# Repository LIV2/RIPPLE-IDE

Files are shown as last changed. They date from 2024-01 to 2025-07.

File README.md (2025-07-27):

# RIPPLE IDE

Zorro 2 IDE Interface for Amiga 2000/3000/4000

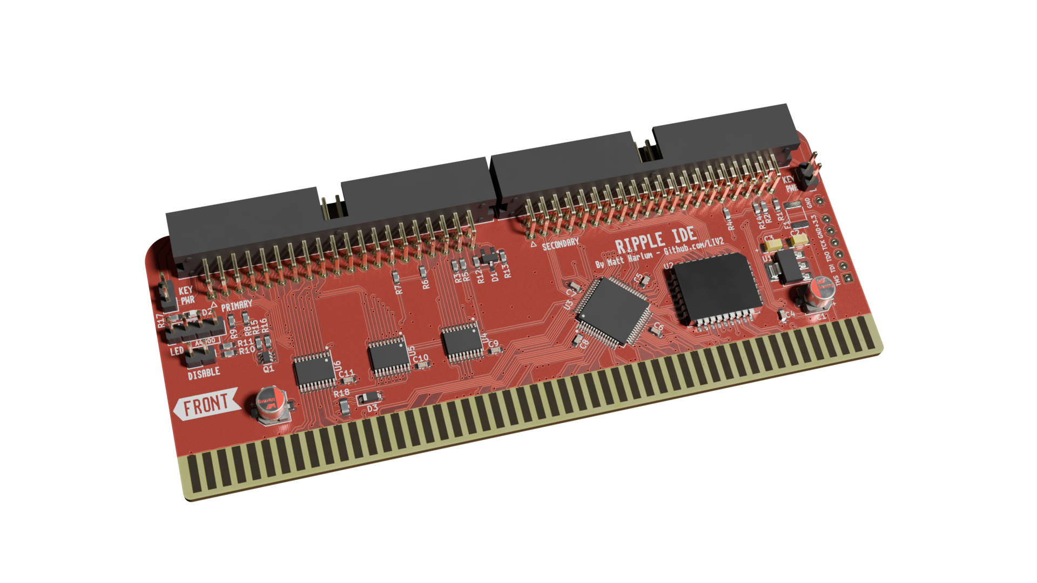
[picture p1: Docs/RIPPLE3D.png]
PCB


## Table of contents
1. [Status](#status)
2. [Features](#features)
3. [Jumpers](#jumpers)
4. [Ordering PCBs](#ordering-pcbs)
5. [Programming](#programming)
6. [Parts list & Links](#parts-list--links)
7. [Revision history](#revision-history)
8. [Special Thanks and Shoutouts](#special-thanks-and-shoutouts)
9. [License](#license)

## Status
Tested and working.

## Features
* Autoboot
* ROM can be updated simply by booting the update disk
* Works with Kickstart 1.3 and up
* [Supports up to 2TB drives](https://github.com/LIV2/lide.device/#large-drive-4gb-support)
* Supports ATAPI Devices (CD/DVD-ROM, Zip disk etc)
* Boot from ZIP/LS-120 etc
* [Boot from CD-ROM](https://github.com/LIV2/lide.device/#boot-from-cdrom)
* SCSI Direct, NSD, TD64 support
* Uses [lide.device](https://github.com/LIV2/lide.device)

For more information on these features please see the [lide.device readme](https://github.com/LIV2/lide.device/blob/master/README.md)

## Jumpers
|Jumper|Function|
|---|---|
|**DISABLE**| Disables the IDE interface|
|**LED**|The LED header has two positions: A2000 and A4000<br /> Plug the HDD LED connector into the one relevant for your machine|
|**KEY PWR**|Closing this jumper enables 5V power on pin 20 for CompactFlash/IDE DOM modules|

## Ordering PCBs
You can find the latest Gerbers attached to the [latest Release](https://github.com/LIV2/RIPPLE-IDE/releases)

I recommend ordering from JLCPCB as this board was designed within their 2-layer specifications  

BOM and Placement files for JLCPCBs assembly service are provided and can be found inside the Gerbers folder and the Gerbers.zip file found under [Releases](https://github.com/LIV2/RIPPLE-IDE/releases)

Recommended options when ordering:
* Thickness: 1.6mm
* Surface Finish: ENIG-RoHS
* Gold Fingers: Yes
* 45°finger chamfered: Yes

## Programming
To program the Flash, simply boot the latest [lide-update.adf](https://github.com/LIV2/lide.device/releases/latest) boot disk

The CPLD can be programmed using a Raspberry Pi [as described by LinuxJedi](https://linuxjedi.co.uk/2020/12/01/programming-xilinx-jtag-from-a-raspberry-pi/)

## Parts list & links
### Rev A4
* [HTML BOM](https://html-preview.github.io/?url=https://github.com/LIV2/RIPPLE-IDE/blob/Rev_A4/Docs/RIPPLE_bom.html)
* [Interactive HTML BOM](https://html-preview.github.io/?url=https://github.com/LIV2/RIPPLE-IDE/blob/Rev_A4/Docs/RIPPLE-ibom.html)

### Rev A3
* [HTML BOM](https://html-preview.github.io/?url=https://github.com/LIV2/RIPPLE-IDE/blob/Rev_A3/Docs/RIPPLE_bom.html)
* [Interactive HTML BOM](https://html-preview.github.io/?url=https://github.com/LIV2/RIPPLE-IDE/blob/Rev_A3/Docs/RIPPLE-ibom.html)

### Rev A2 & A1
* [BOM](Docs/Rev_A2-bom.md)
* [Interactive HTML BOM](https://html-preview.github.io/?url=https://github.com/LIV2/RIPPLE-IDE/blob/Rev_A2/Docs/RIPPLE-ibom.html)

## Revision history
* A4 - Change flash footprint from TSOP to PLCC because the TSOP version is no longer manufactured.
* A3 - Add protection for reverse installation
* A2 - Add bank selection, support loading CDFS from flash
* A1 - Initial release

## Special Thanks and Shoutouts
Thanks to:
* GadgetUK164, Screemo, Sparx, Mafitzee, Pillock for Beta testing the board
* Stefan Reinauer and Chris Hooper for creating the Open-Source A4091 driver which was the inspiration to create lide.device used by RIPPLE

## License
RIPPLE IDE is covered by a GPL 2.0 Only license  


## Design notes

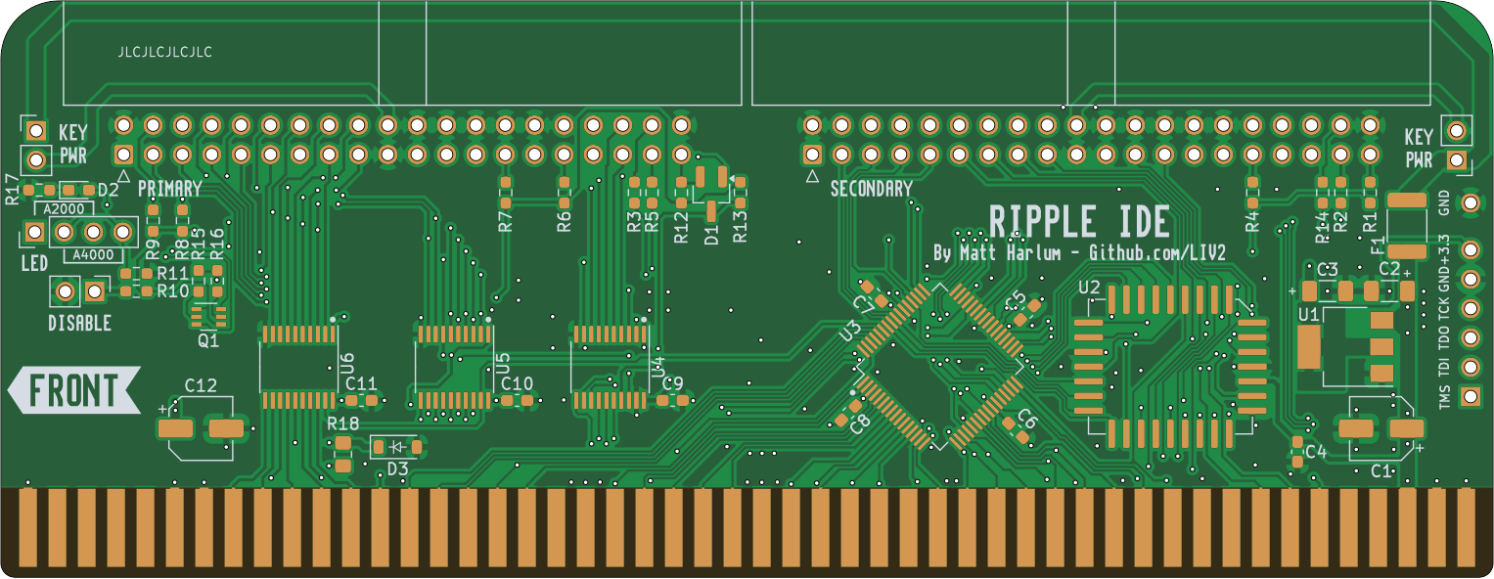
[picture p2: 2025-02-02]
Docs/PCB.png

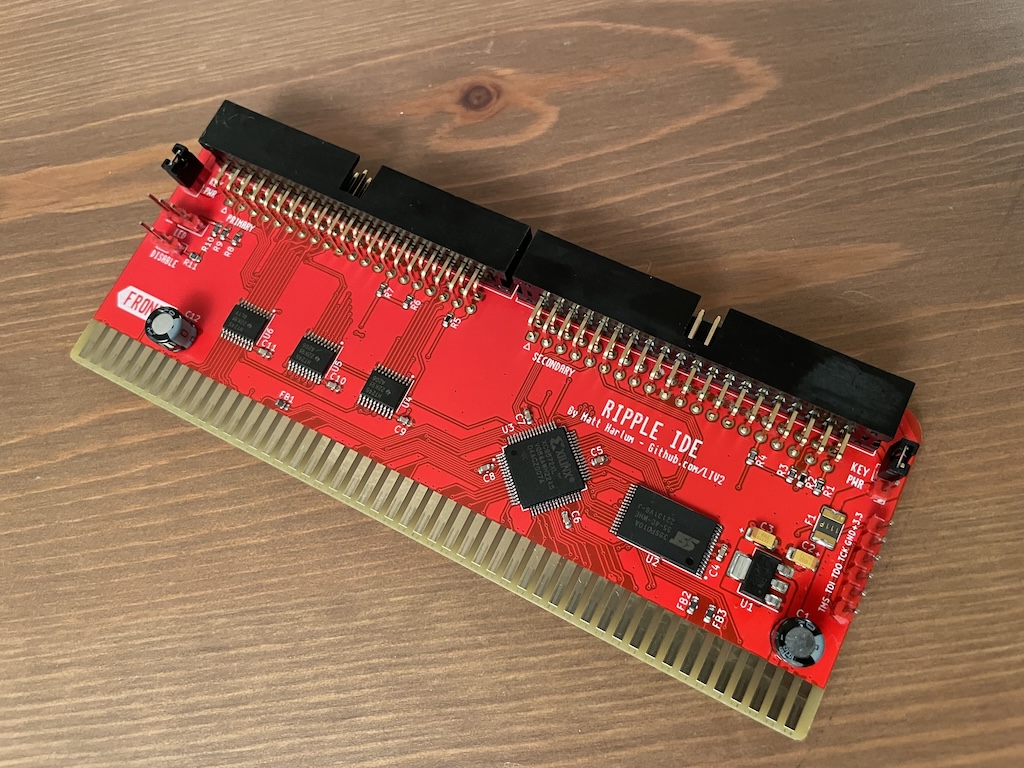
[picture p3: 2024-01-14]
Docs/RIPPLE.jpg

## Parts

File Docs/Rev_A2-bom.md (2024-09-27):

## Bill of Materials
|References|Qty|Value|Footprint|Link|
|---|---|-----|---|----|
|C1,C12|2|47uF 16V|CP_Radial_D5.0mm_P2.50mm|[Mouser](https://www.mouser.com/ProductDetail/667-ECE-A1CKA470I)|
|C3,C2|2|10uF Tantalum|1206|[Mouser](https://www.mouser.com/ProductDetail/581-TAJA106K016R)|
|C9,C4,C5,C7,C11,C8,C6,C10|8|0.1uF Ceramic|0603|[Mouser](https://www.mouser.com/ProductDetail/187-CL10B104KA8NFNC)|
|D1|1|BAT54A|SOT-23|[Mouser](https://www.mouser.com/ProductDetail/621-BAT54A-F)|
|D2|1|SMD LED|0603|[Mouser](https://www.mouser.com/ProductDetail/710-150060VS75000)|
|F1|1|2A Polyfuse|1812|[Mouser](https://www.mouser.com/ProductDetail/652-MF-MSMF110-16-2)|
|J1|1|JTAG Header|1x06 2.54mm Pin Header||
|J4,J3|2|IDE Connector, Right-angle|2x20 2.54mm Right-angle IDC|[Mouser](https://www.mouser.com/ProductDetail/517-30340-5002)|
|J5|1|Disable Jumper|1x02 2.54mm Pin Header||
|J6|1|LED Header|1x04 2.54mm Pin Header||
|J7,J2|2|KEY_PWR|1x02 2.54mm Pin Header||
|Q1|1|BC857BS|SOT-363|[Mouser](https://www.mouser.com/ProductDetail/621-BC857BS-13-F)|
|R10|1|150 Ohm|0603|[Mouser](https://www.mouser.com/ProductDetail/603-RC0603FR-10150RL)|
|R12,R1,R8,R13,R11,R9|6|10K Ohm|0603|[Mouser](https://www.mouser.com/ProductDetail/279-CRGH0603J10K)|
|R14,R5,R2,R3|4|68 Ohm|0603|[Mouser](https://www.mouser.com/ProductDetail/71-CRCW060368R0FKEB)|
|R17|1|330 Ohm|0603|[Mouser](https://www.mouser.com/ProductDetail/603-RT0603DRE07330RL)|
|R6,R4,R15,R16,R7|5|1K Ohm|0603|[Mouser](https://www.mouser.com/ProductDetail/603-RC0603JR-131KL)|
|U1|1|LM1117-3.3|SOT-223-3|[Mouser](https://www.mouser.com/ProductDetail/926-LM1117MP-3.3NOPB)|
|U2|1|SST39SF010|TSOP-32|[Mouser](https://www.mouser.com/ProductDetail/579-SST39010A554CWHE)|
|U3|1|XC9572XL-VQ64|VQFP-64|[Mouser](https://www.mouser.com/ProductDetail/217-C9572XL-10VQG64C)|
|U6,U5,U4|3|74HCT245|TSSOP-20|[Mouser](https://www.mouser.com/ProductDetail/595-SN74HCT245PWR)|

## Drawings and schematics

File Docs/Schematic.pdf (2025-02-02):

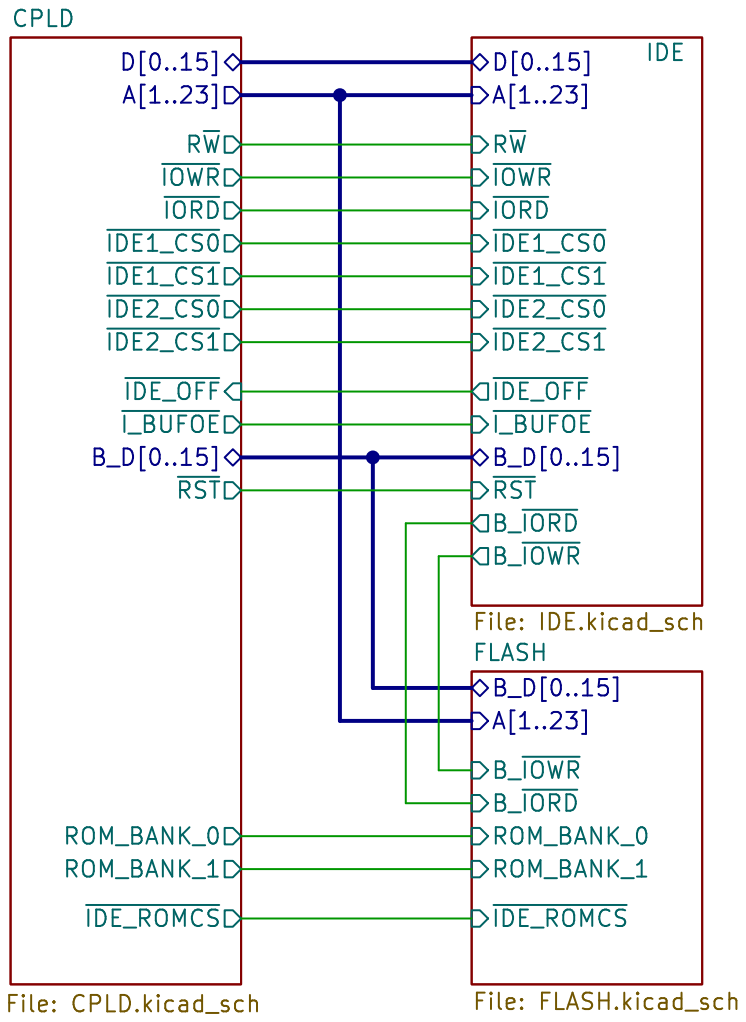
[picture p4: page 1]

Id: 1/4 Title: File: RIPPLE.kicad_sch Sheet: /

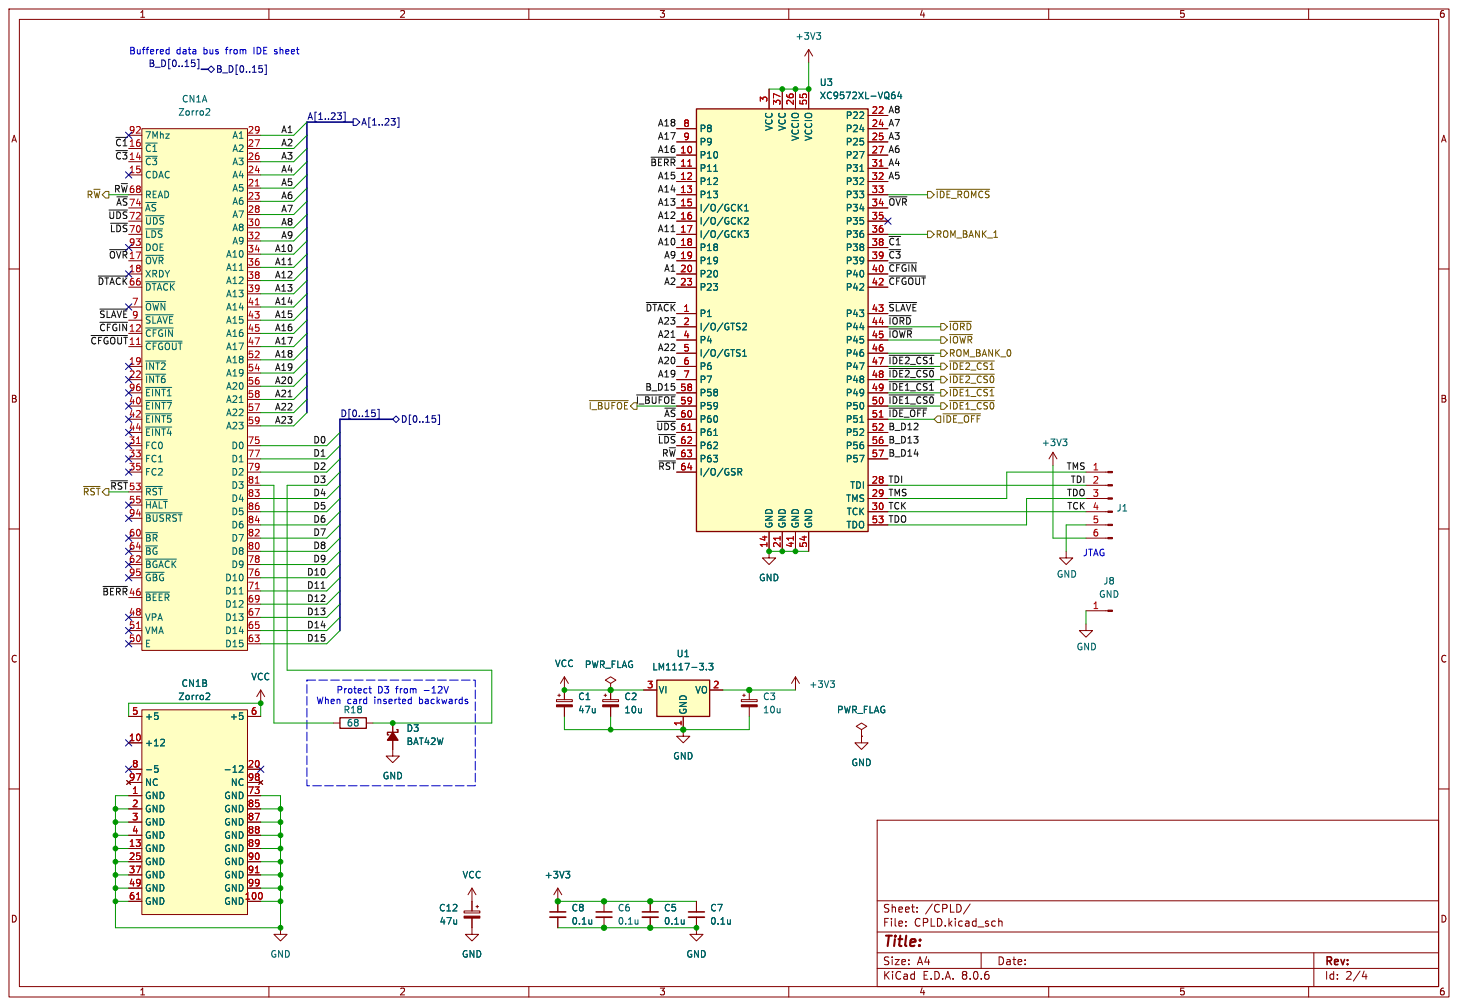
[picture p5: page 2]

Id: 2/4 Title: File: CPLD.kicad_sch Sheet: /CPLD/

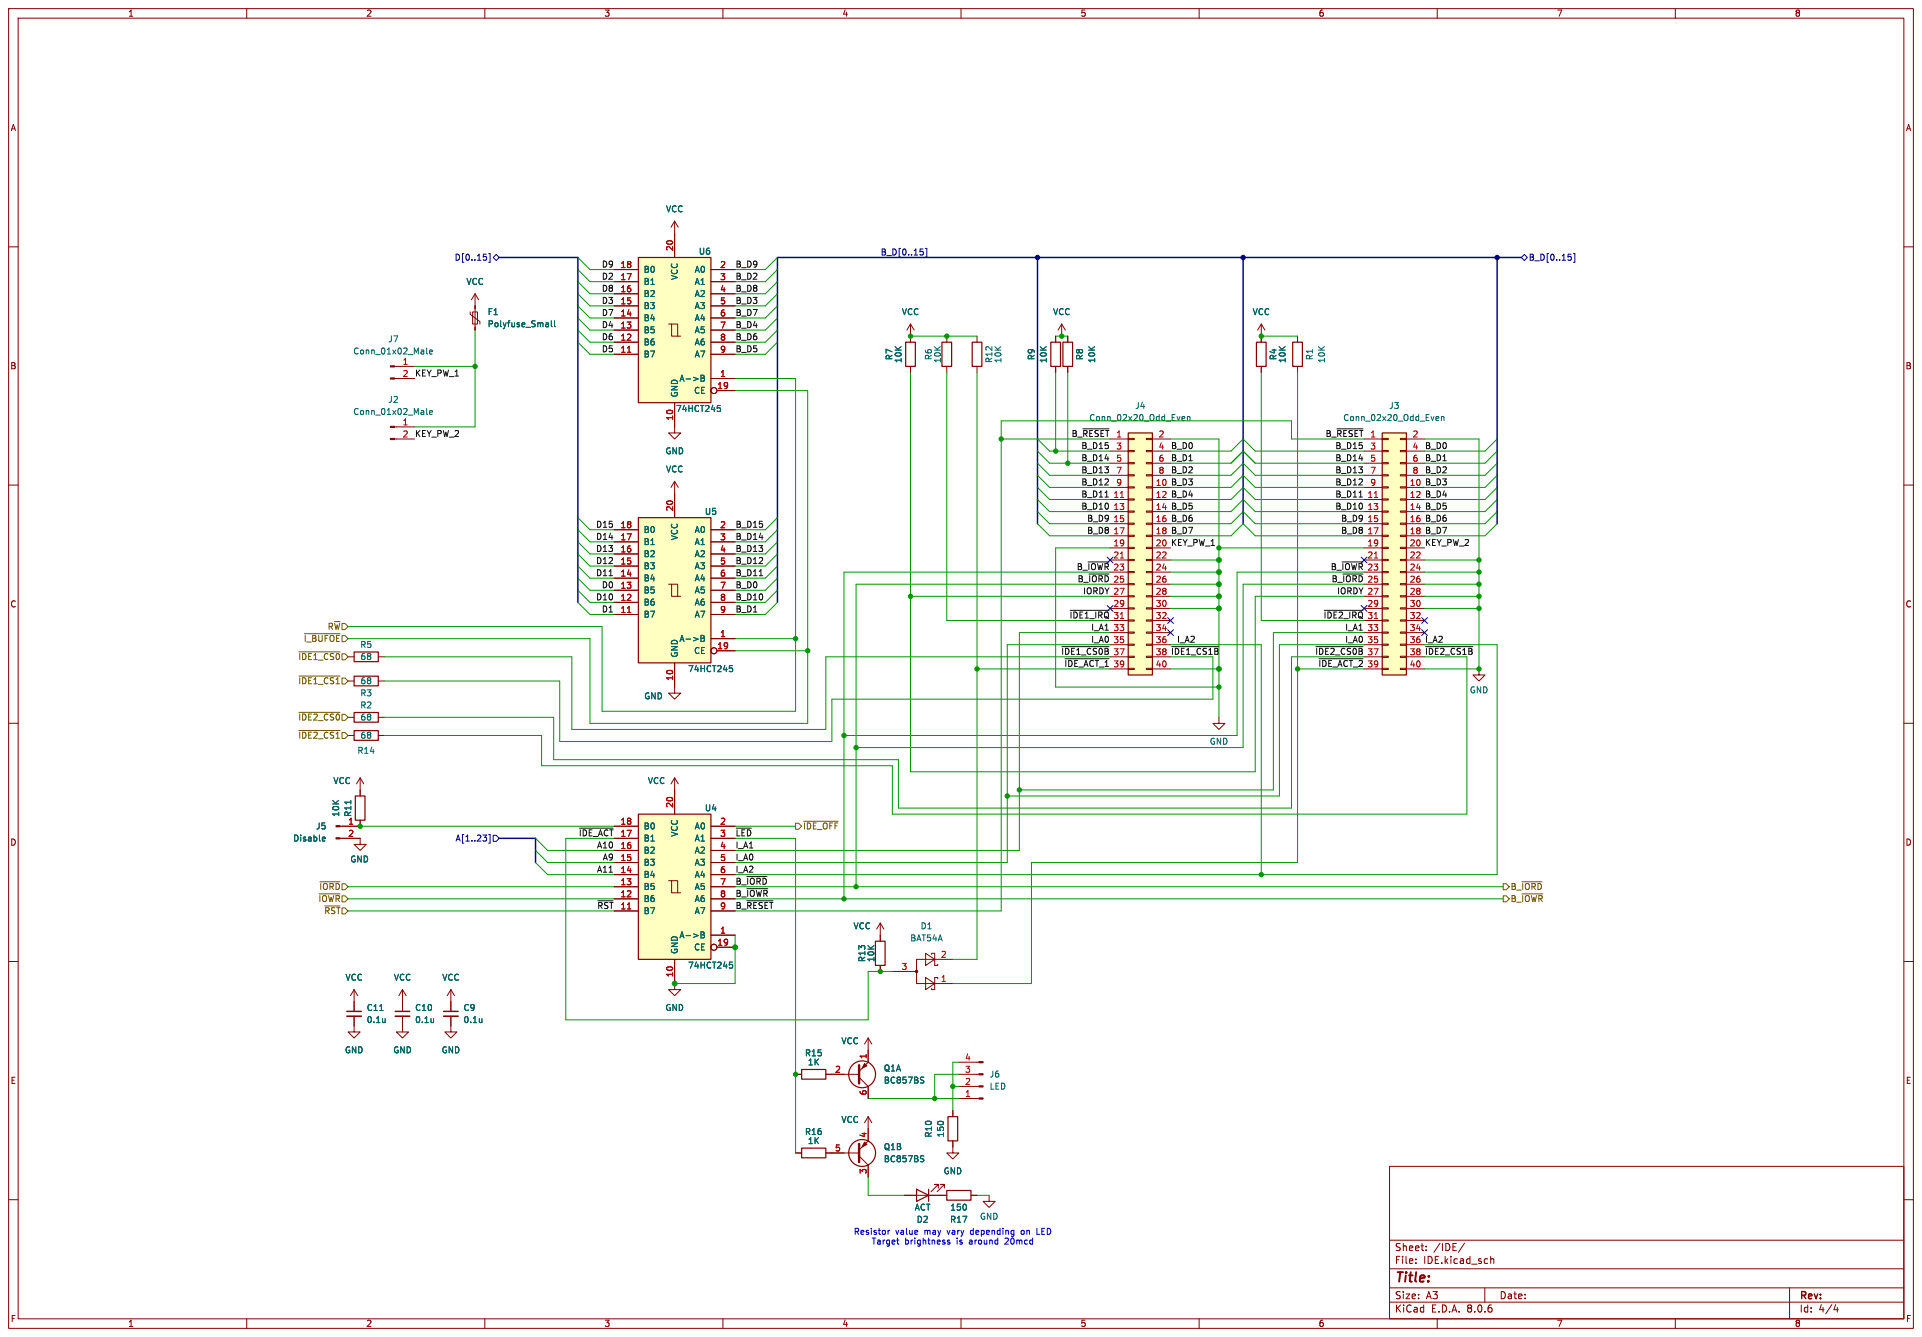
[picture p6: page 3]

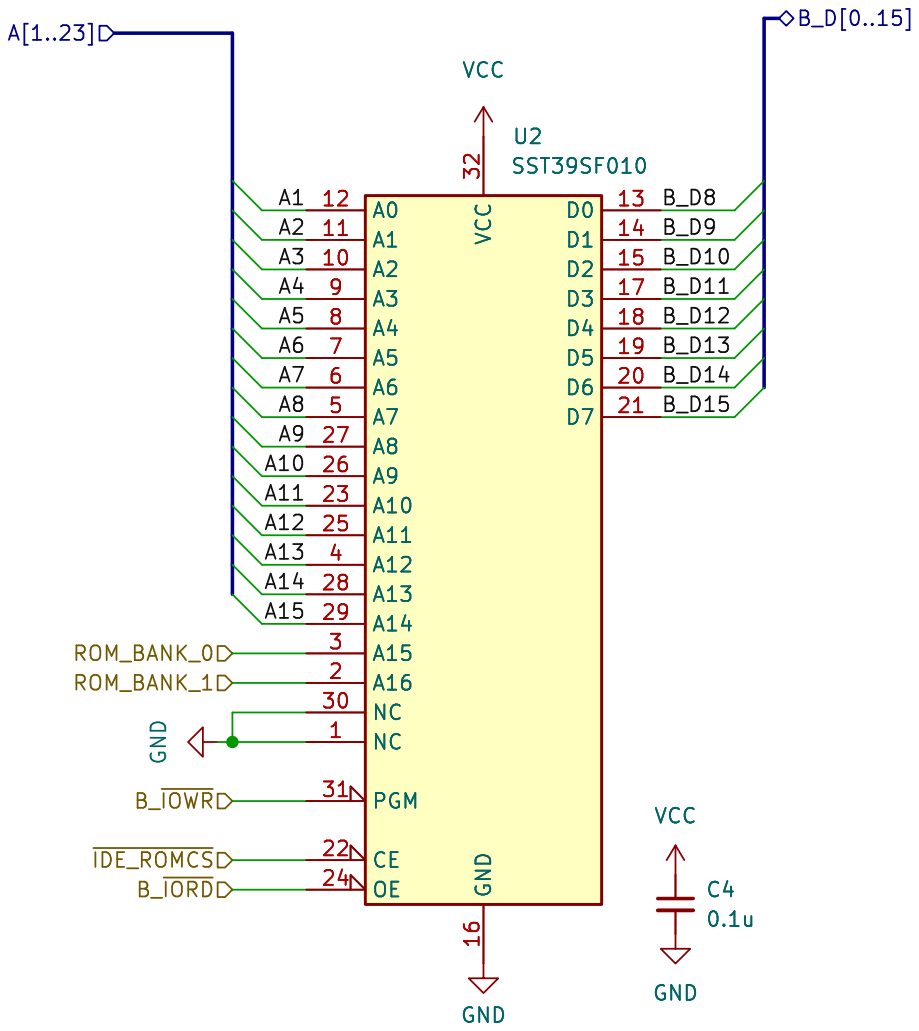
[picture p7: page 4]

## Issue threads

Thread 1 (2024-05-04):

Can i flash/update soldered the SST39SF010?

DirkBree, 2024-05-04:
Of course I can desolder and programme the IC for an update but that is impractical.
Hence the question of whether it can be programmed in circuit in any way?

LIV2, 2024-05-05:
Hi @DirkBree,

You can update the flash at any time simply by booting the latest lide-update boot disk here: https://github.com/LIV2/lide.device/releases

This will program the flash in-system and can do so even if the flash is blank.

I will add this info to the Readme

DirkBree, 2024-05-05:
Hi @LIV2,
oh cool, this is a great solution and thanks for your answer.

Closed 2024-05-15.

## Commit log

2023-02-11 Begin schematic
    [FLASH.kicad_sch, IDE.kicad_sch, LIV2RIDE2K.kicad_pcb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]
2023-06-25 A good start
    [FLASH.kicad_sch, IDE.kicad_sch, LIV2RIDE2K.kicad_pcb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]
2023-07-04 Rename to RIPPLE, do a bunch more routing etc
    [FLASH.kicad_sch, IDE.kicad_sch, LIV2RIDE2K.kicad_pcb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]
2023-07-10 Routing complete, need to double-check
    [FLASH.kicad_sch, IDE.kicad_sch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]
2023-07-12 Move ROM and CPLD data connections to buffered side
    [FLASH.kicad_sch, IDE.kicad_sch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]
2023-07-12 Add pull-up for unconnected CS1 pin of IDE channels
    [IDE.kicad_sch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]
2023-07-13 Change some resistor values from 10K to 1K out of paranoia
    [IDE.kicad_sch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]
2023-07-13 Add JLC Part numbers for IDE Connectors & TH caps
    [IDE.kicad_sch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]
2023-07-16 Move Disable jumper Also route the signal through a buffer to protect the CPLD
    [FLASH.kicad_sch, IDE.kicad_sch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]
2023-07-24 Release Rev_A
    [CPLD.kicad_sch, RIPPLE-B_Cu.gbl, RIPPLE-B_Mask.gbs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]
2023-07-24 Update CPLD Pin mapping and tweak a few things
2023-08-21 Proto A1
    * Fix LED pinout
    * Reduce LED resistor to 150 Ohm
    * Separate Primary/Secondary channel Activity signals
    [IDE.kicad_sch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]
2023-09-20 Rev A1: changes * Dump BUSRST and use regular reset * Ditch the worthless ferrites * Add the gadget header * Add A2000/4000 LED Header
    [IDE.kicad_sch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]
2023-09-25 Add CS1 to both IDE channels
    [IDE.kicad_sch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]
2023-10-07 Fixup LED circuit
    [IDE.kicad_sch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]
2023-10-08 Route bank select pin to ROM
    [FLASH.kicad_sch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]
2023-10-13 Route second bank select
    [FLASH.kicad_sch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]
2023-10-13 Expose second Bank select pin from CPLD
2023-10-20 Fixup pin mapping
2023-10-22 Change R17 from 330 to 1K (IDE LED was insanley bright)
    [IDE.kicad_sch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]
2023-11-18 Add Bill-of-Materials and shoutouts to README
2024-01-14 Fixup flash rotation in pick and place file
    [RIPPLE_cpl_jlc.csv]
2024-03-02 Autoconfig: Don't hardcode upper address bits
    Kickstart may place the board in the Z2 Memory region if IO area is full.
2024-03-02 Add option to build for 64K board size
2024-04-18 RTL: Fix bug in ROM Bank select
    At reset the rom bank select was set to follow addr[16:15] until IDE was activated by a write to any IDE reg.
    After that it reflects the value of the rom_bankSel register
    On a new board with no driver yet in flash this switch would not be triggered, causing the driver to be written to the wrong bank of flash.
    Now the switch will flip on any write to the boards range, the flash identification step will trigger this.
2024-08-28 Update BOM
    * Change LED part number
    * Fix Polyfuse link
2024-08-28 Add protection for reverse installation of the board
    [FLASH.kicad_sch, IDE.kicad_sch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]
2024-08-28 Switch to hand-solder footprints for passives
    [FLASH.kicad_sch, IDE.kicad_sch, RIPPLE.kicad_pcb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]
2024-08-28 Tweak more footprints to make hand assembly easier
    [RIPPLE-B_Cu.gbl, RIPPLE-B_Mask.gbs, RIPPLE-B_Paste.gbp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]
2024-09-12 Move protection diode away from resistor to make it easier to replace
    [RIPPLE-B_Cu.gbl, RIPPLE-B_Mask.gbs, RIPPLE-B_Paste.gbp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]
2024-09-12 Remove RAM.kicad_sch - this was inadvertantly copied from the CIDER project
    [RAM.kicad_sch]
2024-09-13 Fixup part number for D3 and sync schematic & pcb
    [FLASH.kicad_sch, IDE.kicad_sch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]
2024-09-27 Generate HTML BOM with Mouser part links
    [FLASH.kicad_sch, IDE.kicad_sch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]
2024-11-19 BOM: List alternative part numbers for Flash
    [FLASH.kicad_sch, RIPPLE.kicad_pcb]
2024-11-19 BOM: Fixup alternatives for Flash
    [FLASH.kicad_sch, RIPPLE.kicad_pcb]
2025-02-02 Rev A4
    [FLASH.kicad_sch, IDE.kicad_sch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]
2025-09-01 Rev A5: fixup silkscreen
